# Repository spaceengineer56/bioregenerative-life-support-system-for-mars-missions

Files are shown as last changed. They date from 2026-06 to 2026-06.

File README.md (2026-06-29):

# Биорегенеративная система жизнеобеспечения для межпланетного корабля (БСЖМК)

> Концептуальный инженерный проект автономной биорегенеративной системы жизнеобеспечения для длительных межпланетных миссий.

---

## Обзор

Проект представляет собой концепцию **биорегенеративной системы жизнеобеспечения (BLSS)**, рассчитанной на поддержку экипажа из **10 астронавтов** в течение примерно **1000-дневной миссии на Марс**.

Идея системы основана на замкнутом цикле переработки ресурсов с минимизацией зависимости от поставок с Земли. Все модули спроектированы с учётом размещения внутри гермообъёма **Starship SpaceX**.

---

## Состав проекта

В проект входят:

- инженерные расчёты  
- 3D CAD-модели сделанные в KOMPAS-3D
- физический 3D-печатный прототип  
- исследовательская работа  
- презентационные материалы  

---

# Полная система

Полная компоновка биорегенеративной системы жизнеобеспечения.

<p align="center">
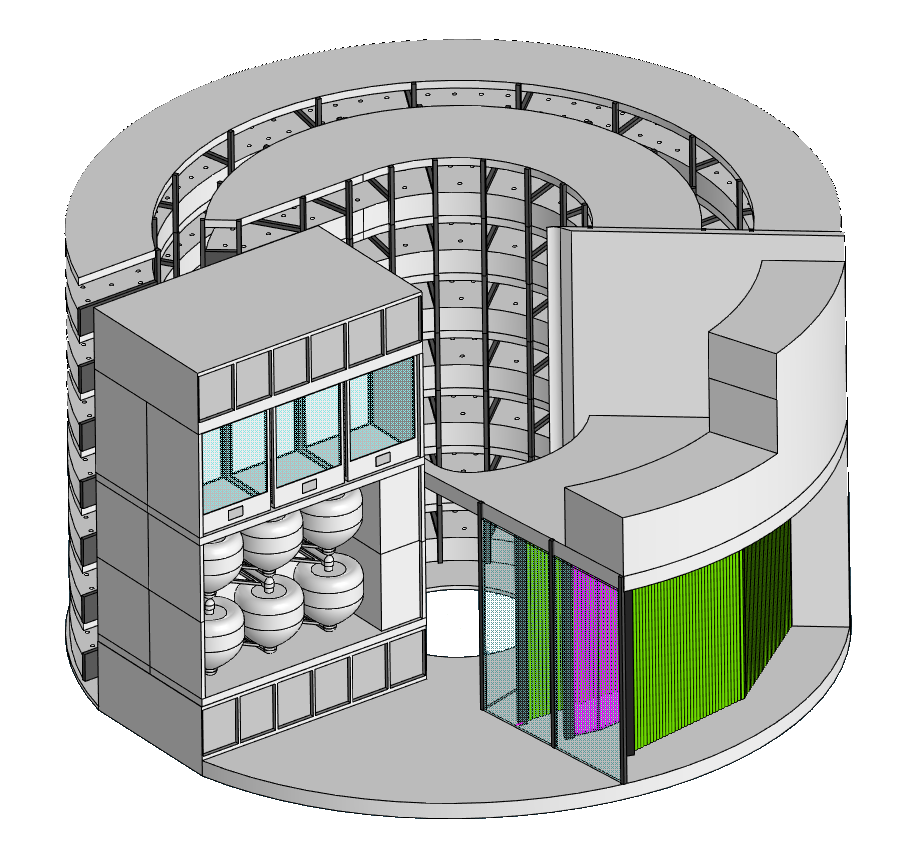
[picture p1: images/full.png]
  
</p>

---

# Основные модули

## Фотобиореактор

Фотобиореактор использует хлореллу для регенерации атмосферы и получения биомассы.

**Функции:**
- выработка кислорода  
- поглощение углекислого газа  
- получение белковой биомассы  

<p align="center">
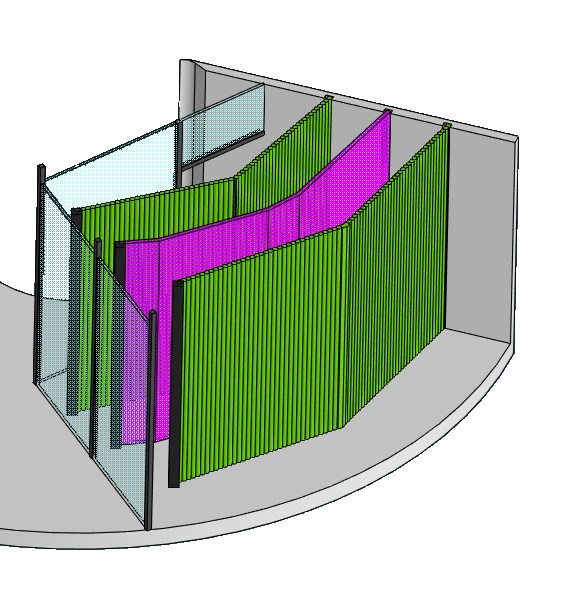
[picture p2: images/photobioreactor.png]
  
</p>

---

## Модуль насекомых

Система переработки органических отходов на основе личинок чёрной львинки.

**Функции:**
- переработка органических отходов  
- получение белка и жиров  
- возврат питательных веществ в цикл  

<p align="center">
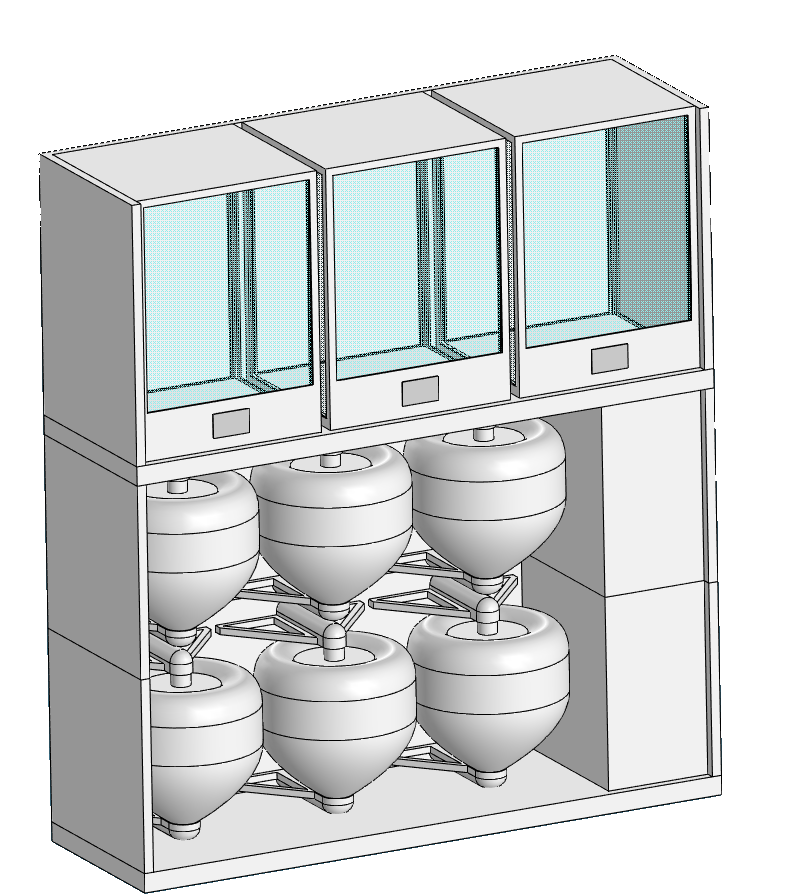
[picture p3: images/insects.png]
  
</p>

---

## Аэропонная теплица

Семиярусная аэропонная теплица для производства пищи.

**Основные культуры:**
- батат
- картошка 

**Дополнительные культуры:**
- пшеница  
- амарант  
- салатные культуры  
- пряные растения
- овощи

<p align="center">
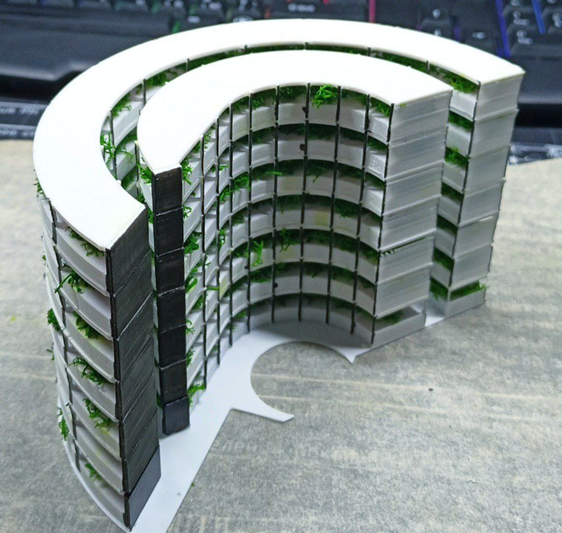
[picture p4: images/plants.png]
  
</p>

---

# Физический прототип

Масштабная демонстрационная модель **1:60**, изготовленная методом **FDM 3D-печати (PLA)**.

Модель была собрана, окрашена и использовалась на защите проекта.

<p align="center">
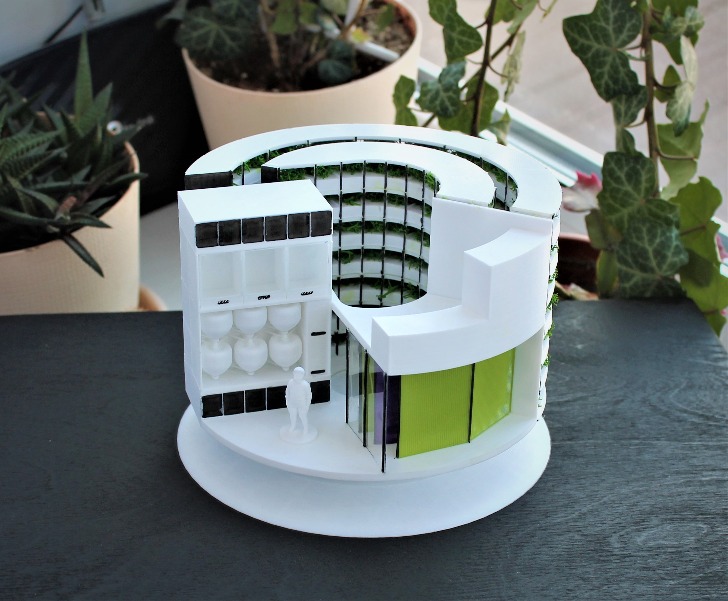
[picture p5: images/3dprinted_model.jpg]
  
</p>

---

# Технические характеристики

| Параметр | Значение |
|---|---|
| Экипаж | 10 человек |
| Длительность миссии | ~1000 суток |
| Объём фотобиореактора | 494 л |
| Производство кислорода | 10.3 кг/сутки |
| Площадь теплицы | 161 м² |
| Модули насекомых | 12 |
| Масштаб прототипа | 1:60 |

---

# Технологии

- KOMPAS-3D  
- инженерные расчёты  
- математическое моделирование  
- FDM 3D-печать  
- PLA  
- CAD-проектирование  

---

# Статус проекта

- ✅ Концепция разработана  
- ✅ Инженерные расчёты выполнены  
- ✅ Создана полная CAD-сборка  
- ✅ Изготовлен физический прототип  

- ⬜ Динамическое моделирование экосистемы  
- ⬜ Система автоматического управления  
- ⬜ CFD и тепловой анализ  

---

# Дальнейшее развитие

Возможные направления развития:

- автоматизация управления средой  
- роботизированное обслуживание модулей  
- оптимизация энергопотребления  
- создание цифрового двойника  
- интеграция с лунными и марсианскими базами  
- долгосрочное моделирование экосистем
- решение проблем с микрогравитацией у фотобиореактора и аэропоники

---

# Примечание

Проект является концептуальным инженерным исследованием и предназначен для образовательных целей.

Система не является готовой к космическому применению, но демонстрирует архитектуру будущих автономных систем жизнеобеспечения.

---

# Автор

**Александр Генералов**

Инженерный концепт биорегенеративной системы жизнеобеспечения для длительных космических миссий.

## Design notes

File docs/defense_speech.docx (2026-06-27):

## Защитная речь

1 слайд: Здравствуйте, уважаемые члены экспертной комиссии! Меня зовут Генералов Александр, и тема моего проекта - «Биорегенеративная система жизнеобеспечения для межпланетного корабля».

2 слайд: Сегодня человечество стоит на пороге колонизации Марса. Однако главная преграда здесь не только радиация и дороговизна, но и проблема с питанием экипажа. Полет в обе стороны и ожидание окна занимают около 1000 дней. Если брать запасы с собой, то на 10 человек потребуется более 150 тонн только еды, воды и кислорода. Это делает миссию почти невозможной.

3 слайд: Цель моей работы - спроектировать систему, которая будет не «складом» ресурсов, а живой фабрикой, восполняющей их прямо на борту. В качестве базы я выбрал габариты корабля Starship диаметром 9 метров.

4 слайд: Чтобы система работала надежно, я выбрал три ключевых биологических звена:

1. Микроводоросли (Хлорелла) – одноклеточные водоросли, лидеры по выработке кислорода.
2. Насекомые (Черная львинка) – похожи на мух, идеальные утилизаторы отходов, превращающие их в жиры и белки.
3. Высшие растения (Батат) – родственник картошки, основной источник углеводов, имеет лучшие показатели урожайности на квадратный метр.

Моя задача как инженера состояла в том, чтобы не просто «расставить горшки с цветами по кораблю», а математически рассчитать, сколько именно нужно этих организмов, чтобы экипаж из 10 человек не испытывал дефицита, и эффективно расположить оборудование в ограниченном объёме.

5 слайд: Мною спроектирована система для разведения хлореллы из 130 герметичных труб. Общий объем составил 494 литра. Мои расчеты показали, что такая установка дает 10 кг кислорода в сутки. Это полностью закрывает потребность 10 человек и дает запас в 2 кг на случай нештатных ситуаций.

6 слайд: Следующая система – устройство для разведения чёрной львинки. Включает в себя террариумы для взрослых особей, инкубаторы для яиц и куколок, и самое интересное – центрифуги для личинок. Главная проблема - отсутствие гравитации, что делает невозможным нормальную вентиляцию субстрата так как массы будут летать по предоставленному объёму и могут забить вентиляцию. Я придумал решение: использовать вращающиеся баки-центрифуги, что устраняет все проблемы. При радиусе 0.4 метра и частоте 33 оборота в минуту внутри создается искусственная гравитация в половину от земной.

7 слайд: Мои расчеты толщины слоя субстрата показывают, что возможно уместить необходимое количество личинок в 6 баков. На случай нештатных ситуаций, решил разместить 12 баков.

8 слайд: Для выращивания батата решил применять аэропонику, так как это позволяет значительно уменьшить массу и увеличить скорость роста. Помимо батата можно выращивать салаты, приправы и цветы. Система дает 2.5 кг углеводов, в сумме с фотобиореактором мы получаем 5 кг углеводов в сутки, что значительно выше необходимого минимума.

9 слайд: На этом слайде представлен расчетный баланс ресурсов системы. В столбике с потребностями – необходимое количество ресурса на 10 человек в сутки, в следующем столбике – максимальное количество, которое производит система жизнеобеспечения. Можно заметить, что везде есть запас, где-то возможно слишком

большой, но в реальности можно будет контролировать производительность.

- 10 слайд: Практическая часть работы заключалась в проектировании системы в Компас-3D и изготовлении макета. Я работал в режиме сборки, чтобы убедиться, что все модули физически вписываются в корпус диаметром 9 метров и высотой 5.5 метров. Для наглядности я изготовил физический макет в масштабе 1 к 60. Для удобства и точности все детали были распечатаны на 3D-принтере, а затем покрашены и склеены. Для возможности рассмотреть систему со всех сторон я использовал вращающуюся базу на подшипнике. Обратите внимание на модель космонавта, которая позволяет оценить реальные размеры системы. Этот макет доказывает, что сложнейшая инженерная система может быть компактно размещена внутри корабля.

11 слайд: Подводя итог, хочу подчеркнуть: разработанная мною модель - это не просто теоретическая концепция. Это просчитанная инженерная структура.

Система полностью автономна по кислороду и обеспечивает запас по углеводам и жирам. Животные и растения не только кормят и поят экипаж, но и создают благоприятный психологический климат, что критически важно в черном вакууме космоса.

В ходе работы остались проблемы с фотобиореактором и аэропоникой. Для стабильной работы в невесомости необходимо сложное оборудование. Но эти проблемы возможно решить, если весь корабль поместить в центрифугу для создания искусственной гравитации.

Биорегенеративные системы - это единственный путь для человечества стать по-настоящему межпланетным видом. Мой проект подтверждает: технически это возможно осуществить в ближайшем будущем.

Спасибо за внимание! Готов ответить на ваши вопросы.

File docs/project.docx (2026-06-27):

Научно-исследовательская работа

Биорегенеративная система жизнеобеспечения для межпланетного корабля

Работу выполнил:

Генералов Александр Дмитриевич

Руководитель:

Генералов Дмитрий Александрович

Орск

2026

Оглавление

1. Введение……………………………………………………………………. | 3
2. Концепция биорегенеративной системы жизнеобеспечения…………… | 5
2.1. Проблема ресурсной автономности марсианской миссии…………...… | 5
2.2 Обоснование выбора базы проектирования…………………………...… | 6
3. Проектирование основных модулей системы…………………………… | 7
3.1. Фотобиореактор: расчет газообмена и конструкция…………………... | 7
3.2. Ферма насекомых: переработка отходов и получение биомассы……… | 8
3.3. Аэропонная оранжерея: культивирование высших растений…………. | 9
4. Техническая реализация и макетирование………………………………... | 10
4.1. Разработка трехмерных моделей в системе Компас-3D……………….. | 10
4.2. Изготовление и сборка демонстрационного макета……………………. | 11
5. Заключение…………………………………………………………………. | 12
6. Список литературы………………………………………………………… | 13

1. Введение

Актуальность работы

Освоение дальнего космоса и подготовка к межпланетным перелетам ставят перед инженерами серьезный вызов: как обеспечить жизнь экипажа в условиях полной изоляции от Земли. Полет к Марсу и обратно вместе с периодом ожидания занимает около трех лет. Транспортировка необходимых запасов на такой срок требует колоссальных грузовых мощностей, что делает миссию технически сложной и дорогой. В связи с этим актуальным становится создание систем воспроизводства ресурсов непосредственно на борту корабля.

Постановка проблемы

Основная трудность заключается в проектировании эффективной замкнутой экосистемы, способной вписаться в габариты современных космических кораблей. В данной работе за основу взяты параметры перспективного корабля Starship компании SpaceX. При внешнем диаметре корпуса 9 метров и высоте полезного жилого пространства около 18 метров, необходимо компактно разместить биологические установки так, чтобы они полностью покрывали потребности группы из 10 человек.

Объект и предмет исследования

Объектом научно-исследовательской работы являются системы жизнеобеспечения для межпланетных кораблей. Предметом исследования выступает расчет параметров и пространственное моделирование модулей (на основе микроводорослей, насекомых и растений) применительно к внутреннему объему корабля Starship.

Цель работы

Теоретически обосновать инженерную структуру биорегенеративной системы в рамках заданных габаритов и изготовить её наглядный маломасштабный макет.

Задачи:

1. Изучить физиологические потребности экипажа из 10 человек в кислороде и пище.
2. Выбрать биологические компоненты для переработки отходов и синтеза ресурсов (хлорелла, черная львинка, батат).
3. Рассчитать необходимые габариты установок, исходя из площади и объема жилого отсека корабля диаметром 9 метров.
4. Спроектировать трехмерные модели всех узлов системы в программе Компас-3D.
5. Изготовить масштабный макет из пластика методом 3D-печати для демонстрации компоновки модулей.

Методы исследования: анализ данных из научных источников, математическое моделирование, 3D-проектирование и макетирование.

2. Концепция биорегенеративной системы жизнеобеспечения

2.1. Проблема ресурсной автономности марсианской миссии

Обеспечение жизнедеятельности экипажа в условиях длительного космического полета является наиболее сложной задачей при планировании миссии на Марс. В отличие от околоземных станций (МКС), где запасы регулярно пополняются грузовыми кораблями, марсианская экспедиция должна обладать беспрецедентным уровнем автономности.

Согласно баллистическим расчетам по траектории Гомана, среднее время миссии составляет около 1000 суток (33 месяца). Основная проблема заключается в массе необходимых расходных материалов. По данным Института медико-биологических проблем РАН (ИМБП РАН), на одного человека в сутки требуется значительный объем кислорода, воды и пищи. При расчете на экипаж из 10 человек суммарный вес запасов превышает 150 тонн. Доставка такой массы с Земли технически очень сложна и экономически неэффективна.

Решением этой проблемы является переход к биорегенеративным системам жизнеобеспечения (БСЖ). Принцип БСЖ заключается в замыкании круговорота веществ: продукты жизнедеятельности человека (углекислый газ, органические отходы) перерабатываются биологическими организмами обратно в кислород и пищу. Это позволяет не только снизить массу корабля, но и создать психологически комфортную среду для экипажа.

2.2. Обоснование выбора базы проектирования

Для того чтобы теоретические расчеты имели прикладной характер, в данной работе в качестве платформы для размещения системы выбран перспективный многоразовый корабль Starship компании SpaceX. На сегодняшний день это единственный проект корабля, способный к межпланетному перелёту и обладающий достаточным внутренним объемом для размещения полнофункциональной биорегенеративной станции.

Таким образом, проектируемая система рассматривается не как абстрактная установка, а как целевое оборудование для конкретного типа межпланетного транспорта. Использование параметров Starship позволяет точно рассчитать компоновку модулей, которая в дальнейшем была визуализирована в 3D-модели и воплощена в масштабном макете.

### 3. Проектирование основных модулей системы

3.1. Фотобиореактор: расчет газообмена и конструкция

Фотобиореактор предназначен для регенерации атмосферы и синтеза белка с использованием микроводоросли хлореллы.

Конструкция и расчет объема: Установка спроектирована в системе Компас-3D и представляет собой блок из 130 герметичных труб диаметром 44 мм и длиной 2,5 м.

- Объем одной трубы: V = 3,14 × 0,022 × 0,022 × 2,5 × 1000 = 3,8 литра.
- Общий объем системы: 3,8 × 130 = 494 литра.

Производительность (суточные показатели): На основе данных проекта «435нм» произведен расчет выхода ресурсов:

- Прирост биомассы: 0,016 × 494 = 7,9 кг хлореллы.
- Генерация кислорода (O2): 1,3 × 7,9 = 10,3 кг (при норме на 10 человек - 8,4 кг).
- Поглощение углекислого газа (CO2): 1,8 × 7,9 = 14,2 кг.
- Пищевая ценность: 4 кг белка и 2,4 кг углеводов.

Таким образом, технические параметры фотобиореактора позволяют не только регенерировать атмосферу, но и обеспечивать экипаж первичной биологической массой. Компактное размещение трубчатых элементов дает возможность рационально использовать внутренний объем, оставляя свободное пространство для работы и отдыха. Применение автоматизированного контроля за освещением и циркуляцией суспензии минимизирует участие человека в работе установки, превращая реактор в стабильный и автономный узел жизнеобеспечения.

3.2. Ферма насекомых: переработка отходов и получение биомассы

В качестве разводимой культуры в проекте выбрана чёрная львинка. Конструктивно ферма состоит из террариумов для взрослых особей (имаго), инкубаторов для яиц и баков-центрифуг для выращивания личинок.

Инженерное решение и расчет вращения: Для решения проблемы дефицита гравитации в космосе личинки содержатся в специальных баках-центрифугах. При вращении субстрат прижимается к стенкам, что упрощает газообмен и вентиляцию. Для создания искусственной гравитации в 0.5g при радиусе бака 0.4 м была рассчитана необходимая угловая скорость: √(0.5 × 9.81 / 0.4) ≈ 3.5 рад/с ≈ 33 об/мин.

Расчет производительности: На основе данных из научного журнала Universum определены суточные показатели выхода биомассы для нужд экипажа:

- Выход сухих личинок: 0.8 × 1.2 / 0.1387 ≈ 6.9 кг в сутки.
- Выход живых личинок: 6.9 / 0.35 ≈ 19.7 кг в сутки.

Баланс субстрата в системе: Для поддержания такого темпа роста требуется ежедневная подача органических отходов:

- 19.7 × 1.6 = 31.52 кг субстрата в сутки.
- 31.52 × 10 = 315.2 кг субстрата постоянно находится в системе (учитывая десятидневный цикл роста личинок).

Параметры бака и толщина слоя: Для эффективного содержания важно соблюдать нормы плотности субстрата. Расчет объема смеси на один из шести основных баков составил 0.0875 м³, что позволило вычислить толщину слоя на стенках: 0.4 - √(0.4² - 0.0875 / (3.14 × 0.4)) ≈ 10 см. Этот показатель соответствует рекомендуемым 10–15 см, что предотвращает перегрев личинок и обеспечивает им стабильный доступ к воздуху.

Для производства необходимого количества жиров физически достаточно 6 баков. Однако для повышения надежности всей системы и возможности обслуживания отдельных узлов в проект заложено 12 аналогичных установок.

3.3. Аэропонная оранжерея: культивирование высших растений

Растительный модуль предназначен для производства сложных углеводов и витаминов, необходимых для сбалансированного рациона экипажа. Конструктивно оранжерея состоит из 7 этажей аэропонных установок, что позволяет получить 161 квадратный метр активной площади для выращивания культур.

Основным источником углеводов в системе выбран батат. Кроме него, для разнообразия питания и восполнения микроэлементов в проект заложены дополнительные культуры: амарант, пшеница, различные виды салатов и приправы.

Расчет производительности: На основе средних показателей урожайности для закрытых аэропонных систем был произведен расчет выхода питательных веществ: 75 × 0.22 ≈ 16 г/м² углеводов в сутки. Для всей доступной площади модуля (161 м²) общая производительность составляет: 161 × 16 ≈ 2.5 кг углеводов в сутки.

Анализ суммарной эффективности: Для обеспечения жизнедеятельности экипажа из 10 человек требуется около 3.2 кг углеводов в сутки. Согласно проектным расчетам, оранжерея и фотобиореактор вместе генерируют почти 5 кг углеводов в сутки (2.5 кг от оранжереи и 2.4 кг от реактора).

Основным источником углеводов в системе выступает оранжерея. Углеводы, получаемые из фотобиореактора, служат резервным ресурсом, который гарантированно восполняет любой возможный недобор и создает запас прочности системы при увеличении физических нагрузок экипажа.

## 4. Техническая реализация и макетирование

4.1. Моделирование узлов в системе Компас-3D

При переходе к этапу трехмерного проектирования в системе Компас-3D за основу были взяты реальные габариты жилого отсека корабля Starship. Цифровая модель всей системы жизнеобеспечения была выстроена в натуральную величину: итоговый диаметр конструкции составил 9 метров, а общая высота всех модулей - 5,5 метра.

Использование режима сборки позволило в реальном масштабе оценить плотность размещения оборудования. Такой подход подтвердил, что выбранные габариты позволяют не только компактно разместить все три биологических модуля, но и оставить достаточное пространство для перемещения экипажа и доступа к техническим узлам.

Процесс моделирования был разделен на несколько этапов:

1. Проектирование фотобиореактора. На основе расчетных данных (внутренний диаметр 44 мм) был создан базовый сегмент трубы. В режиме сборки эти сегменты были размножены до 130 единиц и объединены в общую систему циркуляции с учетом возможности подвода коммуникаций. Для управления режимами освещения реактора предусмотрена стеклянная перегородка с функцией затемнения (смарт-стекло).
2. Разработка фермы черной львинки. Здесь режим сборки позволил точно выставить зазоры для свободного вращения 12 баков-центрифуг. Также были смоделированы стеллажи для эргономичного размещения террариумов и инкубаторов.
3. Моделирование аэропонной оранжереи. На финальном этапе в общую сборку были добавлены семиэтажные стеллажи. В целях оптимизации внутреннего пространства корабля аэропонные установки размещены по дуге в два ряда. Для обеспечения доступа экипажа и удобства обслуживания между рядами предусмотрен технологический проход шириной 60 см.
4. Планировка рабочего пространства. Свободное пространство, оставшееся после компоновки основных модулей, отведено под специализированную зону для хранения инструментария и расходных материалов, необходимых для обслуживания биорегенеративной системы.

4.2. Создание физического макета биорегенеративной системы жизнеобеспечения

Для материализации проекта и создания наглядной демонстрационной модели был выбран масштаб 1:60. Исходя из этого коэффициента, диаметр распечатанного макета составил 150 мм. Выбор такого масштаба обусловлен необходимостью соблюсти баланс: макет остается достаточно компактным для транспортировки и презентации, но при этом сохраняет высокую точность детализации.

Процесс изготовления включал в себя следующие шаги:

- 3D-печать. Все ключевые элементы, спроектированные в Компасе (секции реактора, барабаны фермы, ярусы оранжереи), были распечатаны из PLA-пластика на 3D-принтере Flyingbear Ghost 6.
- Сборка и монтаж. Распечатанные детали были зашлифованы, окрашены и склеены в единую конструкцию. Использование пластика позволило сделать макет легким, но при этом достаточно детализированным для демонстрации внутренних узлов.
- Визуализация. Для наглядности разные функциональные зоны были выделены цветом: балки стеллажей окрашены в черный цвет, элементы фотобиореактора - в зеленый, а зоны освещения выделены фиолетовым. Для реалистичной имитации растительности в оранжерее использован стабилизированный мох.
- Презентабельность и масштаб. Для обеспечения всестороннего обзора макета БСЖМК сконструирована вращающаяся база на подшипниковой опоре. Чтобы зрительно оценить реальные габариты системы и эргономику внутреннего пространства, на макете закреплена фигурка космонавта, выполненная в строгом соответствии с масштабом конструкции.

### 5. Заключение

В ходе выполнения данной научно-исследовательской работы все поставленные цели были успешно достигнуты. Была спроектирована и обоснована автономная система жизнеобеспечения, способная поддерживать жизнедеятельность экипажа из 10 человек в течение 1000-дневной миссии.

На основе проведенных инженерных расчетов и моделирования можно сделать следующие выводы:

1. Фотобиореактор на базе хлореллы объемом 494 литра полностью справляется с регенерацией атмосферы. Его производительность по кислороду (10,3 кг в сутки) перекрывает потребности экипажа и создает необходимый резерв безопасности. Кроме того, реактор служит источником растительного белка.
2. Модуль энтомологической переработки на основе черной львинки успешно решает задачу утилизации органики. Использование 12 баков-центрифуг позволяет получать 1,12 кг жиров в сутки, что является критически важным для сбалансированного рациона в условиях длительной изоляции.
3. Аэропонная оранжерея площадью 161 квадратный метр вместе с фотобиореактором суммарно обеспечивают около 5 кг углеводов в сутки при норме в 3,2 кг. Это доказывает, что система способна самостоятельно снабжать экипаж пищей без необходимости везти с собой огромные запасы провизии с Земли.

Разработанный макет демонстрирует возможную структуру биорегенеративной системы жизнеобеспечения для длительных межпланетных миссий. Использование биологических компонентов, таких как растения и насекомые, открывает новые возможности в космонавтике. Проведённые расчёты показали, что подобная система может самостоятельно обеспечивать экипаж кислородом и пищей, снижая массу необходимых запасов и повышая автономность миссии. Кроме того, наличие растений может оказывать положительное психологическое влияние на экипаж во время длительного пребывания в космосе.

Таким образом, биорегенеративные системы жизнеобеспечения являются перспективным направлением для будущих межпланетных экспедиций. Работа над макетом в системе Компас-3D и его физическое воплощение подтвердили техническую реализуемость предложенных идей и их готовность к дальнейшему развитию.

### 6. Список литературы

### 1. Синяк, Ю. Е. (2008). Системы жизнеобеспечения обитаемых космических объектов (прошлое, настоящее и будущее). Доступно по ссылке: http://www.imbp.ru/webpages/win1251/science/uchsov/docl/2008/Sinjak_speach.html

2. Шаенко, А. Ю. (2023). Биотехническая система обеспечения газового состава атмосферы лунной базы на основе микроводорослей. Доступно по ссылке: https:// (https://docs.google.com/presentation/d/1fhkI-y-zyXAAe3G4RmqY4vzgqxQgFG3P/edit?slide=id.p1)docs.google.com/presentation/d/1fhkI-y-zyXAAe3G4RmqY4vzgqxQgFG3P/edit?slide=id.p1#slide=id.p1

### 3. Туйчиев, К. С. (2023). Выращивание личинок чёрной львинки (Hermetia illucens Linnaeus) на пшеничных отрубях и показатели их продуктивности. Доступно по ссылке: https://7universum.com/pdf/nature/6(108)%20[25.05.2023]/Tuychiev.pdf

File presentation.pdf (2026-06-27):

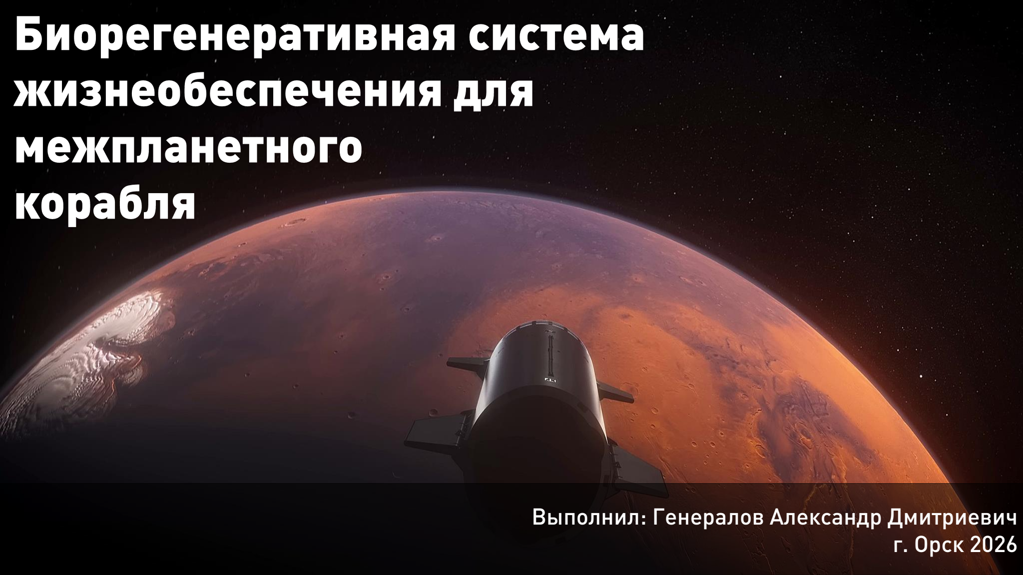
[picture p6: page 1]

Выполнил: Генералов Александр Дмитриевич г. Орск 2026

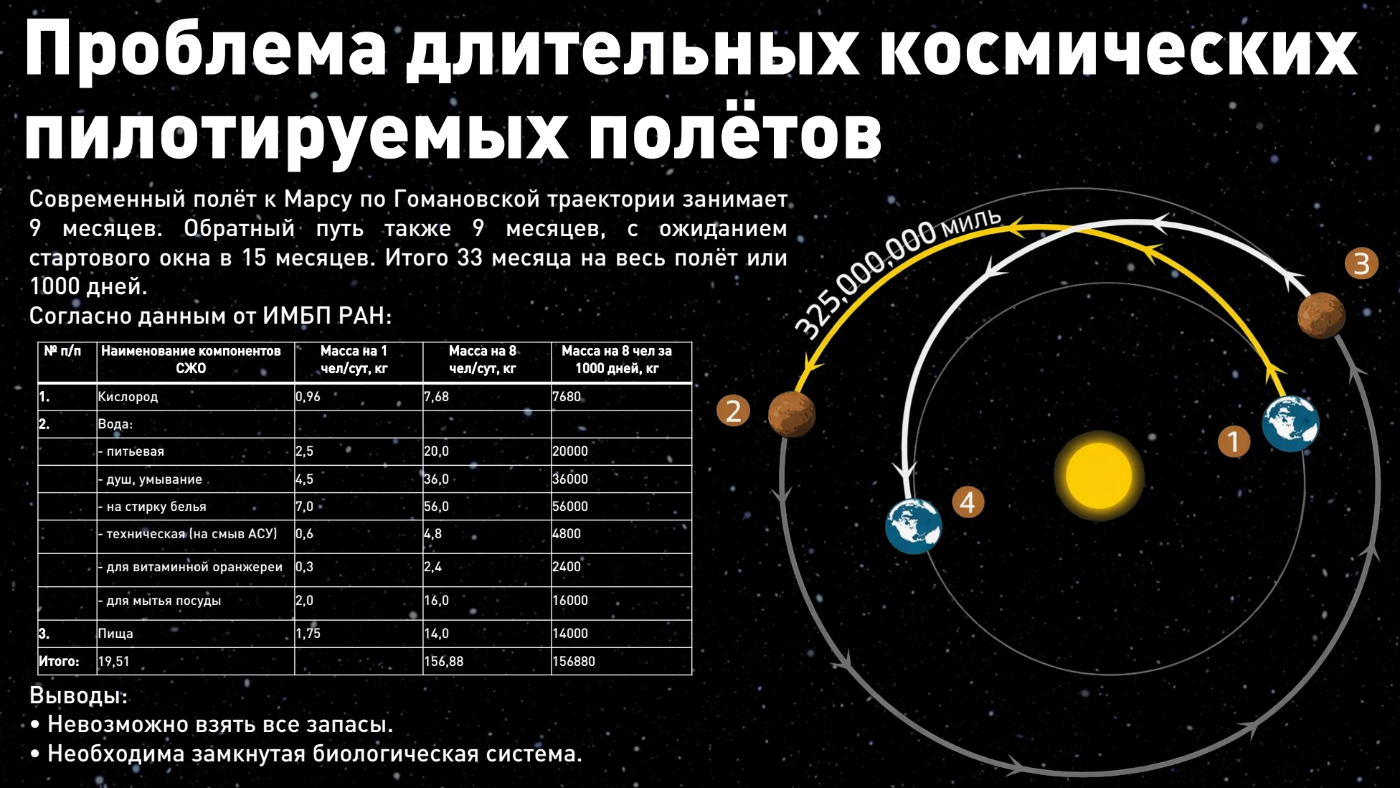
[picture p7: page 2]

Современный полёт к Марсу по Гомановской траектории занимает 9 месяцев. Обратный путь также 9 месяцев, с ожиданием стартового окна в 15 месяцев. Итого 33 месяца на весь полёт или 1000 дней.
Согласно данным от ИМБП РАН:

Выводы:
- Невозможно взять все запасы.
- Необходима замкнутая биологическая система.
№ п/п | Наименование компонентов СЖО | Масса на 1 чел/сут, кг | Масса на 8 чел/сут, кг | Масса на 8 чел за 1000 дней, кг
1. | Кислород | 0,96 | 7,68 | 7680
2. Вода:
| - питьевая | 2,5 | 20,0 | 20000
| - душ, умывание | 4,5 | 36,0 | 36000
| - на стирку белья | 7,0 | 56,0 | 56000
| - техническая (на смыв АСУ) | 0,6 | 4,8 | 4800
| - для витаминной оранжереи | 0,3 | 2,4 | 2400
| - для мытья посуды | 2,0 | 16,0 | 16000
3. | Пища | 1,75 | 14,0 | 14000
Итого: | 19,51 | | 156,88 | 156880

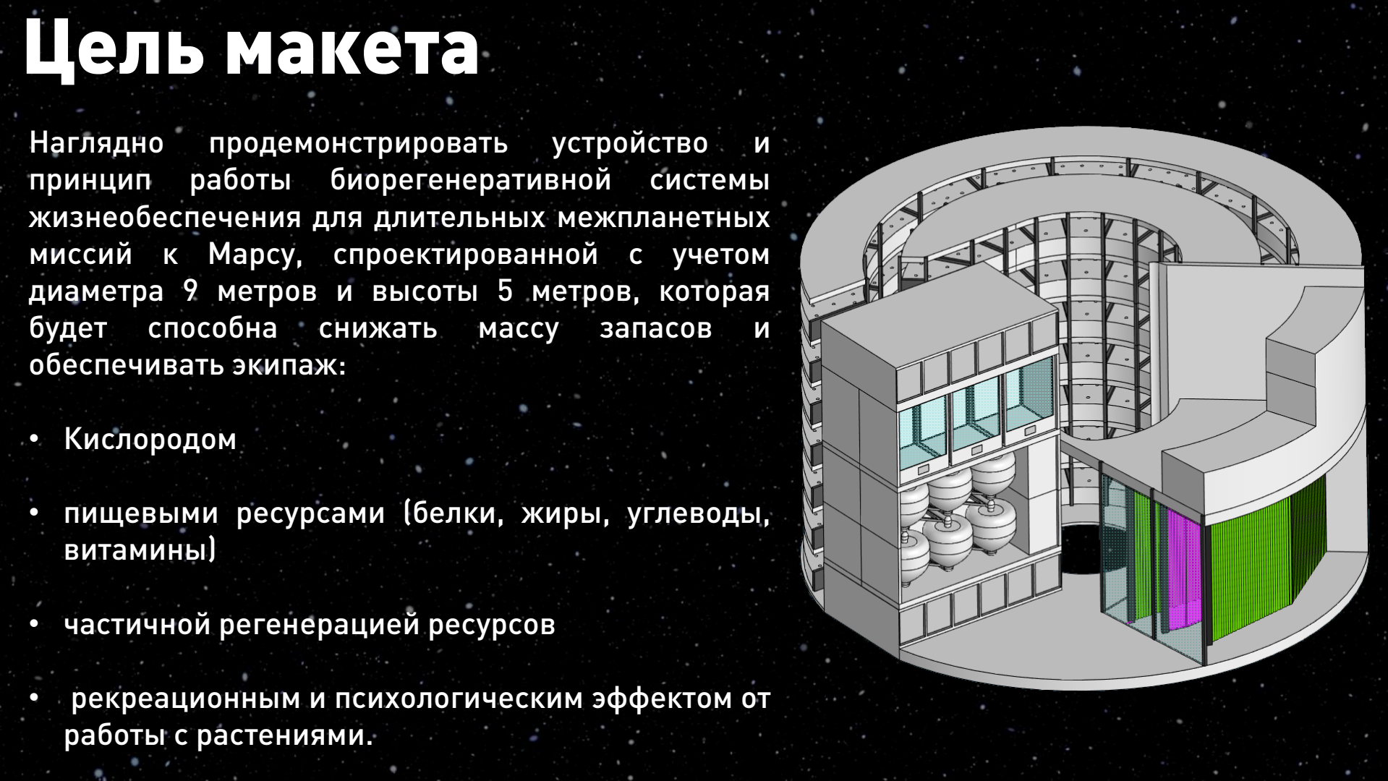
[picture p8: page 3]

Наглядно | продемонстрировать | устройство | и
принцип | работы | биорегенеративной | системы
жизнеобеспечения для длительных межпланетных миссий к Марсу, спроектированной с учетом диаметра 9 метров и высоты 5 метров, которая
будет | способна | снижать | массу | запасов | и
обеспечивать экипаж:
- Кислородом
- пищевыми ресурсами (белки, жиры, углеводы, витамины)
- частичной регенерацией ресурсов
- рекреационным и психологическим эффектом от работы с растениями.

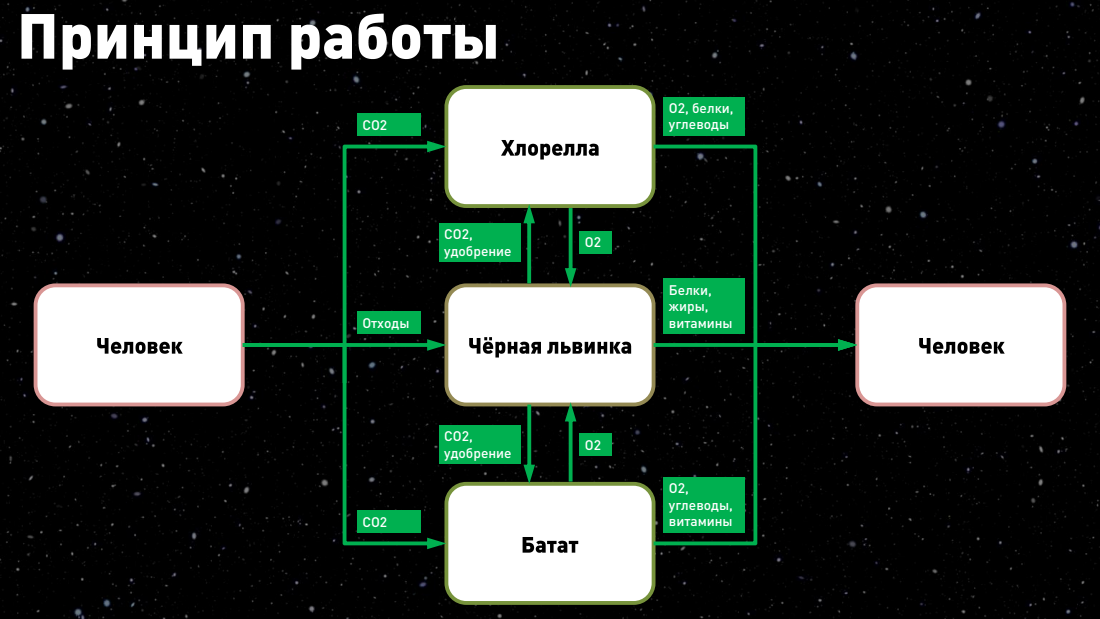
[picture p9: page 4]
O2 CO2, удобрение; Отходы; Белки, жиры, витамины; O2, белки, углеводы; O2, углеводы, витамины

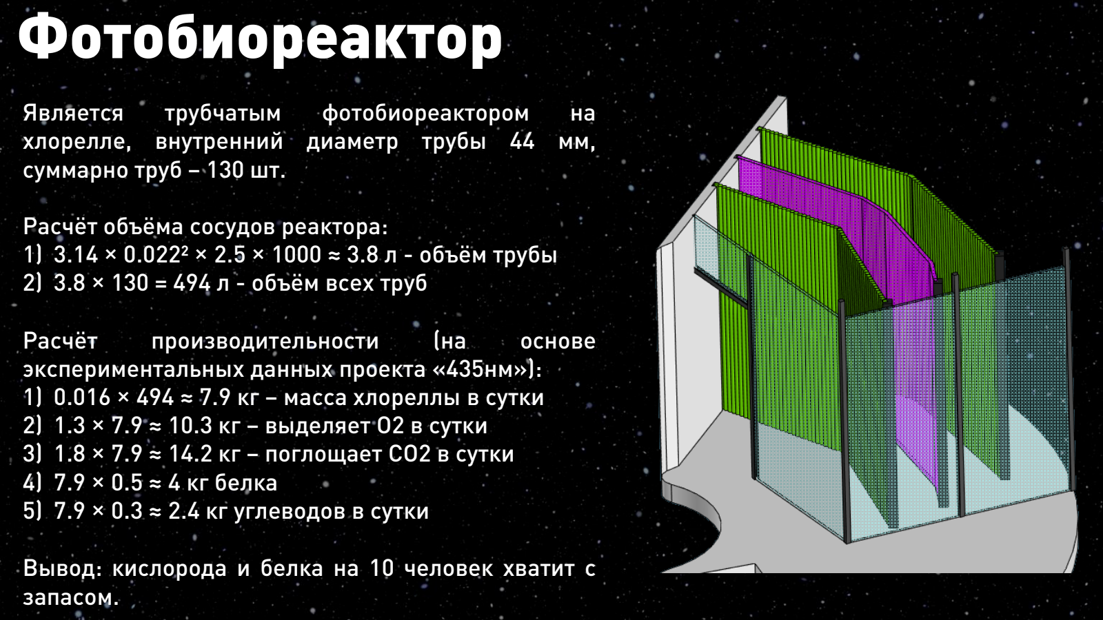
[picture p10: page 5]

Является | трубчатым | фотобиореактором | на
хлорелле, внутренний диаметр трубы 44 мм, суммарно труб – 130 шт.

Расчёт объёма сосудов реактора:
1) 3.14 × 0.022² × 2.5 × 1000 ≈ 3.8 л - объём трубы
2) 3.8 × 130 = 494 л - объём всех труб
Расчёт | производительности | (на | основе
экспериментальных данных проекта «435нм»):
1) 0.016 × 494 ≈ 7.9 кг – масса хлореллы в сутки
2) 1.3 × 7.9 ≈ 10.3 кг – выделяет O2 в сутки
3) 1.8 × 7.9 ≈ 14.2 кг – поглощает CO2 в сутки
4) 7.9 × 0.5 ≈ 4 кг белка
5) 7.9 × 0.3 ≈ 2.4 кг углеводов в сутки

Вывод: кислорода и белка на 10 человек хватит с запасом.

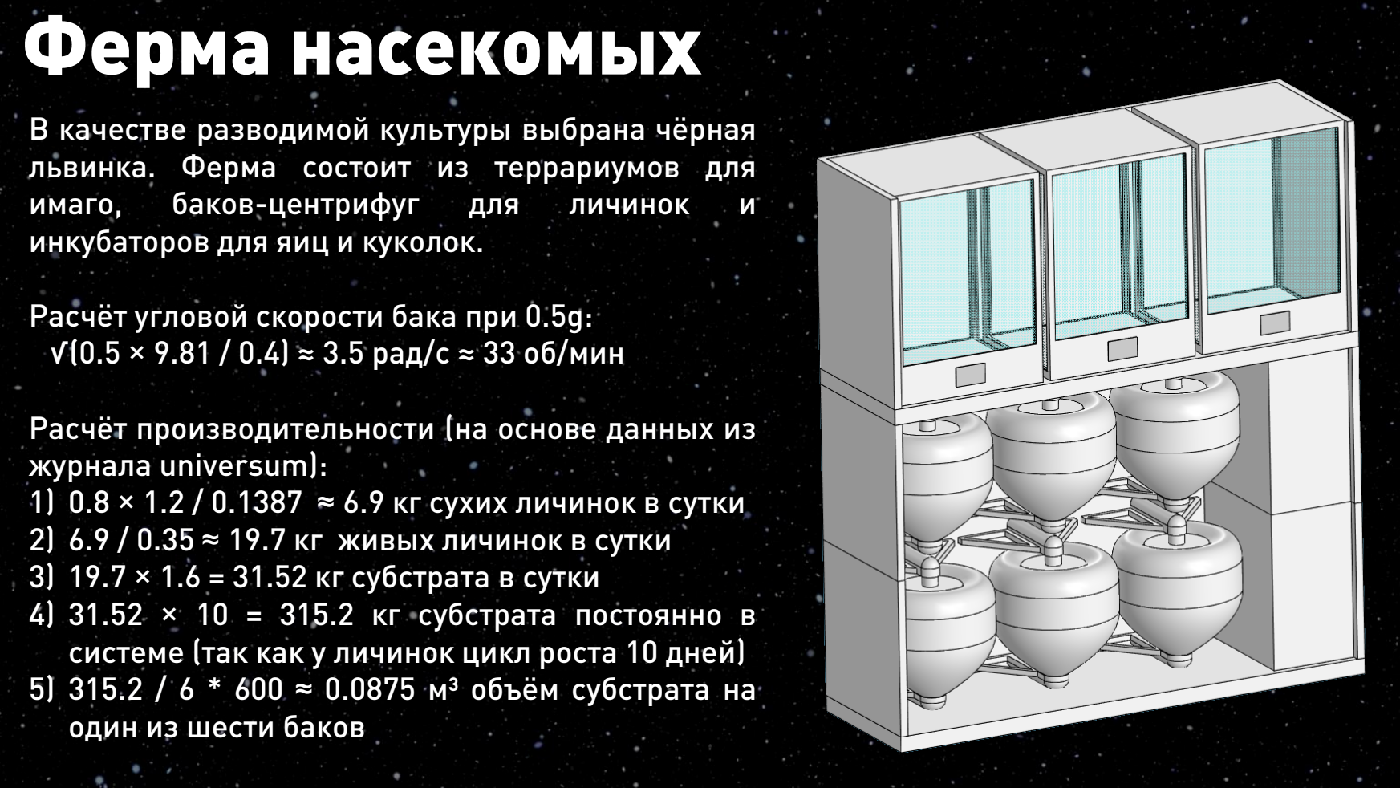
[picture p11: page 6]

В качестве разводимой культуры выбрана чёрная львинка. Ферма состоит из террариумов для
имаго, | баков-центрифуг | для | личинок | и
инкубаторов для яиц и куколок.

Расчёт угловой скорости бака при 0.5g:
√(0.5 × 9.81 / 0.4) ≈ 3.5 рад/с ≈ 33 об/мин

Расчёт производительности (на основе данных из журнала universum):
1) 0.8 × 1.2 / 0.1387 ≈ 6.9 кг сухих личинок в сутки
2) 6.9 / 0.35 ≈ 19.7 кг живых личинок в сутки
3) 19.7 × 1.6 = 31.52 кг субстрата в сутки
4) 31.52 × 10 = 315.2 кг субстрата постоянно в системе (так как у личинок цикл роста 10 дней)
5) 315.2 / 6 * 600 ≈ 0.0875 м³ объём субстрата на один из шести баков

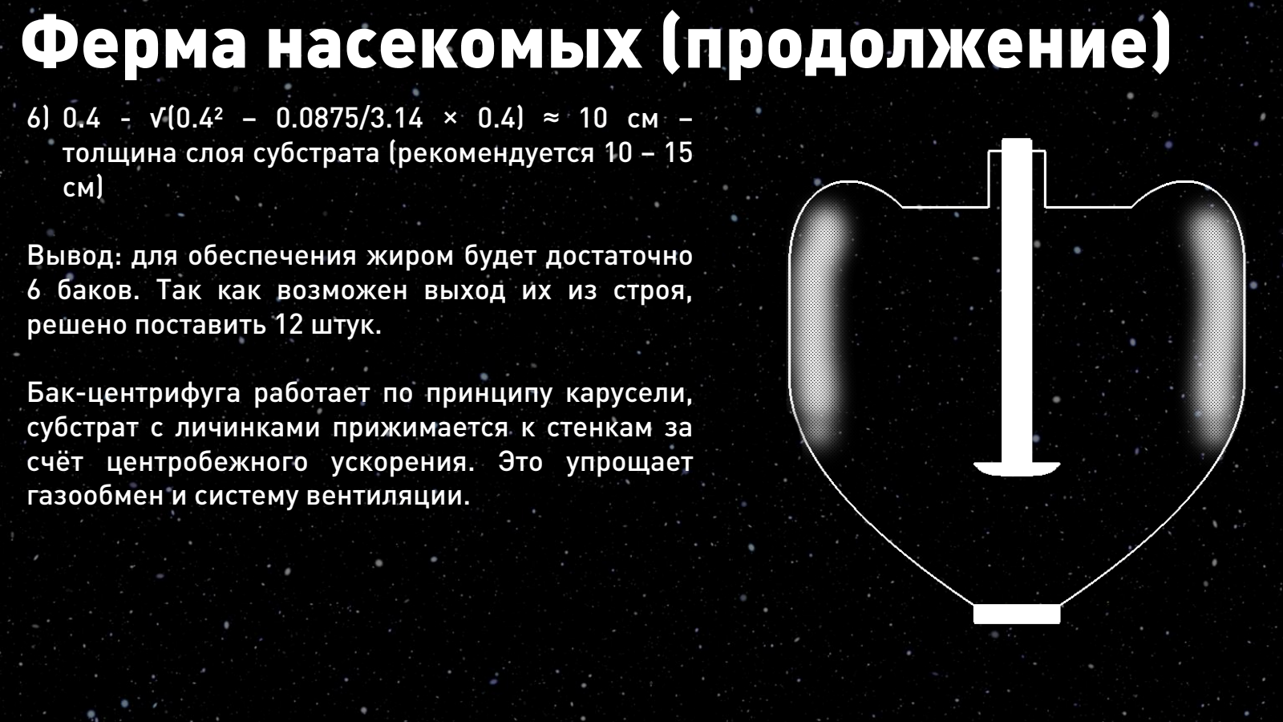
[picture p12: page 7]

6) 0.4 - √(0.4² – 0.0875/3.14 × 0.4) ≈ 10 см – толщина слоя субстрата (рекомендуется 10 – 15 см)

Вывод: для обеспечения жиром будет достаточно 6 баков. Так как возможен выход их из строя, решено поставить 12 штук.

Бак-центрифуга работает по принципу карусели, субстрат с личинками прижимается к стенкам за счёт центробежного ускорения. Это упрощает газообмен и систему вентиляции.

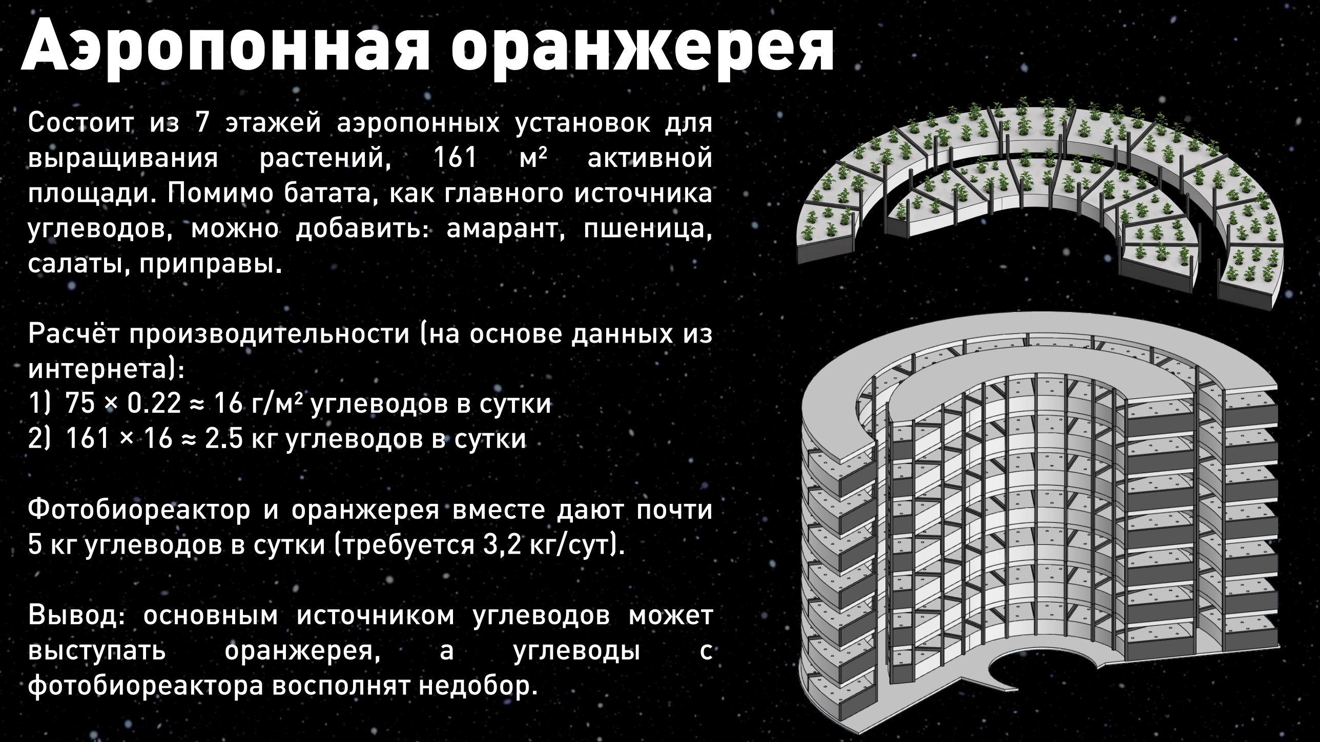
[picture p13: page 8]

Состоит из 7 этажей аэропонных установок для
выращивания | растений, | 161 | м² | активной
площади. Помимо батата, как главного источника углеводов, можно добавить: амарант, пшеница, салаты, приправы.

Расчёт производительности (на основе данных из интернета):
1) 75 × 0.22 ≈ 16 г/м² углеводов в сутки
2) 161 × 16 ≈ 2.5 кг углеводов в сутки

Фотобиореактор и оранжерея вместе дают почти 5 кг углеводов в сутки (требуется 3,2 кг/сут).

Вывод: основным источником углеводов может
выступать | оранжерея, | а | углеводы | с
фотобиореактора восполнят недобор.

Ресурс | Потребность | Производство
O2 | 8.4 кг | 10.3 кг

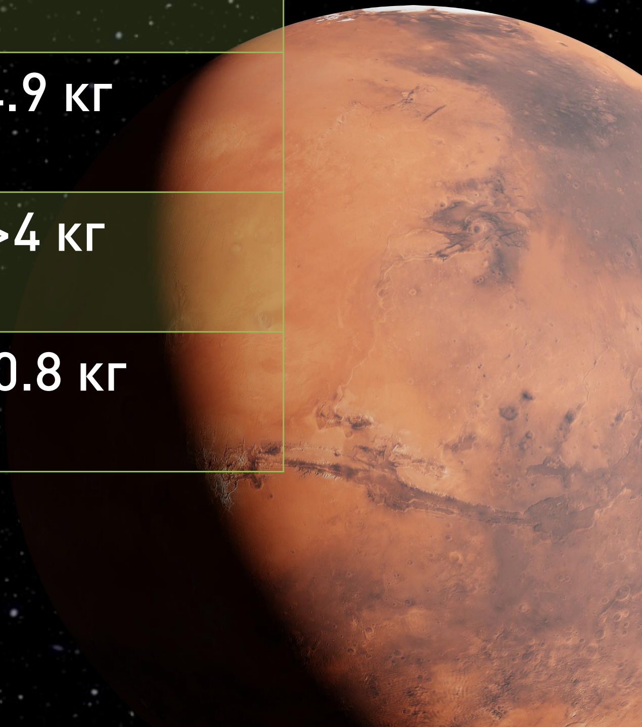
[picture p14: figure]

Углеводы | 3.2 кг | 4.9 кг
Белки | 1 кг | >4 кг
Жиры | 0.8 кг | >0.8 кг

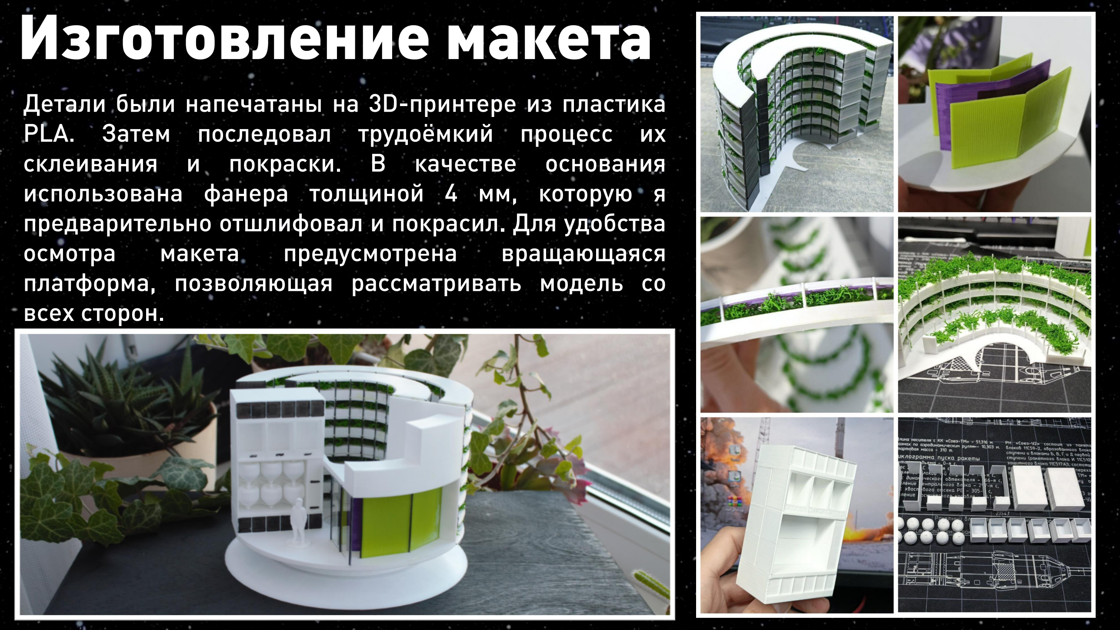
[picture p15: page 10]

Детали были напечатаны на 3D-принтере из пластика PLA. Затем последовал трудоёмкий процесс их
склеивания | и | покраски. | В | качестве | основания
использована фанера толщиной 4 мм, которую я предварительно отшлифовал и покрасил. Для удобства
осмотра | макета | предусмотрена | вращающаяся
платформа, позволяющая рассматривать модель со всех сторон.

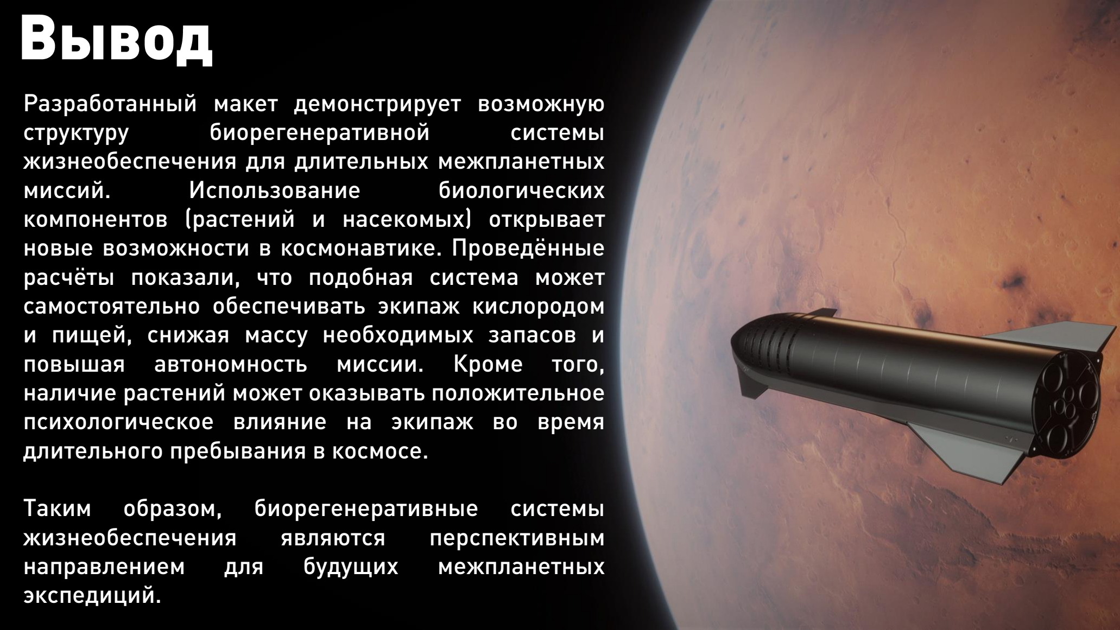
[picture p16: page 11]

Разработанный макет демонстрирует возможную
структуру | биорегенеративной | системы
жизнеобеспечения для длительных межпланетных
миссий. | Использование | биологических
компонентов (растений и насекомых) открывает новые возможности в космонавтике. Проведённые расчёты показали, что подобная система может самостоятельно обеспечивать экипаж кислородом и пищей, снижая массу необходимых запасов и
повышая | автономность | миссии. | Кроме | того,
наличие растений может оказывать положительное психологическое влияние на экипаж во время длительного пребывания в космосе.
Таким | образом, | биорегенеративные | системы
жизнеобеспечения | являются | перспективным
направлением | для | будущих | межпланетных
экспедиций.

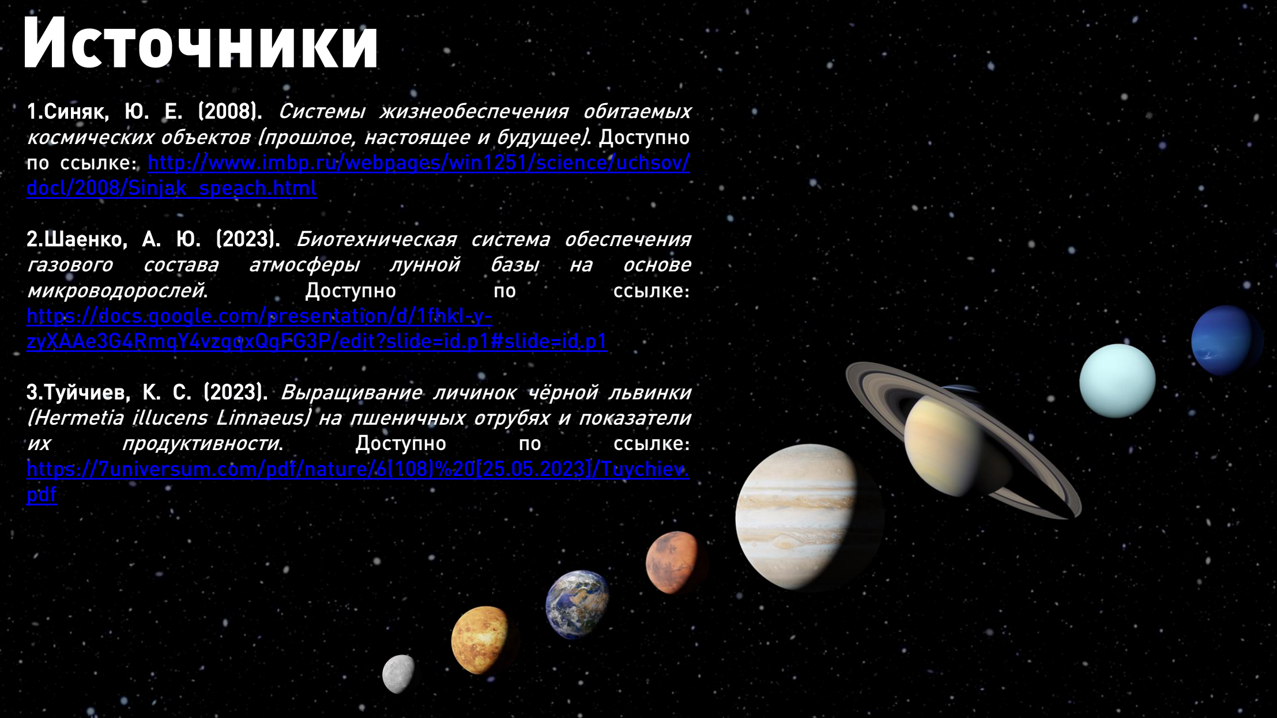
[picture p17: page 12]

1.Синяк, Ю. Е. (2008). Системы жизнеобеспечения обитаемых космических объектов (прошлое, настоящее и будущее). Доступно по ссылке: http://www.imbp.ru/webpages/win1251/science/uchsov/docl/2008/Sinjak_speach.html (http://www.imbp.ru/webpages/win1251/science/uchsov/docl/2008/Sinjak_speach.html)

2.Шаенко, А. Ю. (2023). Биотехническая система обеспечения
газового | состава | атмосферы | лунной | базы | на | основе
микроводорослей. | Доступно | по | ссылке:
https://docs.google.com/presentation/d/1fhkI-y-zyXAAe3G4RmqY4vzgqxQgFG3P/edit?slide=id.p1#slide=id.p1 (https://docs.google.com/presentation/d/1fhkI-y-zyXAAe3G4RmqY4vzgqxQgFG3P/edit?slide=id.p1)

3.Туйчиев, К. С. (2023). Выращивание личинок чёрной львинки (Hermetia illucens Linnaeus) на пшеничных отрубях и показатели
их | продуктивности. | Доступно | по | ссылке:
https://7universum.com/pdf/nature/6(108)%20[25.05.2023]/Tuychiev. pdf

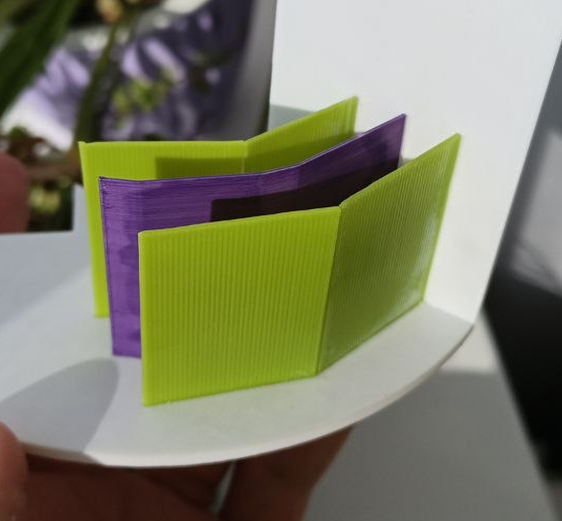
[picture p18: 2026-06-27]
images/Рисунок2.png

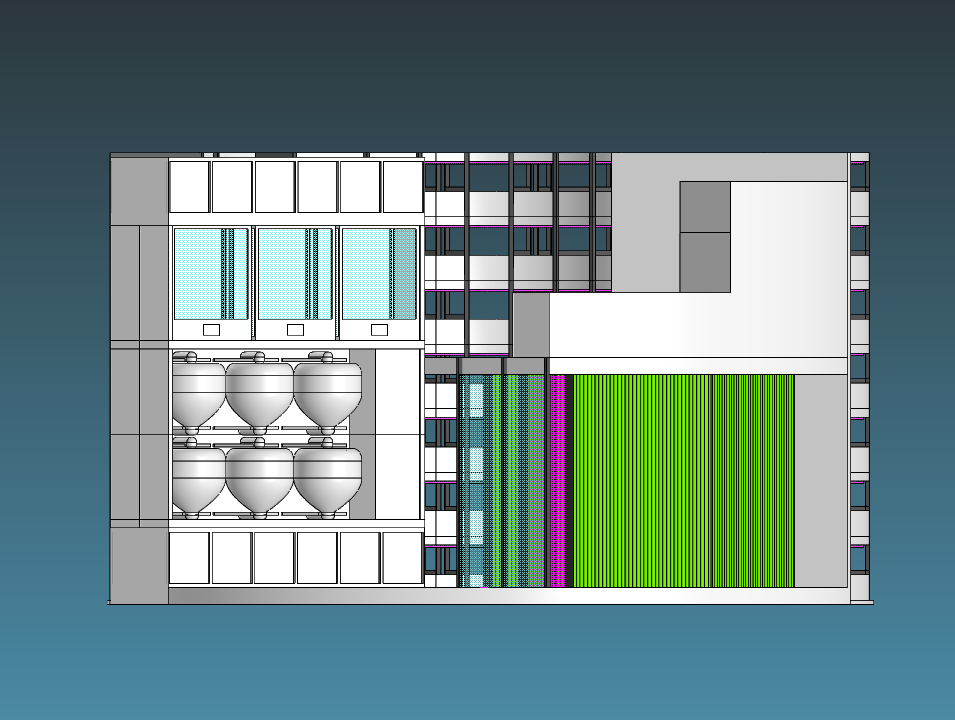
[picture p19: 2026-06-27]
images/Screenshot_5.png

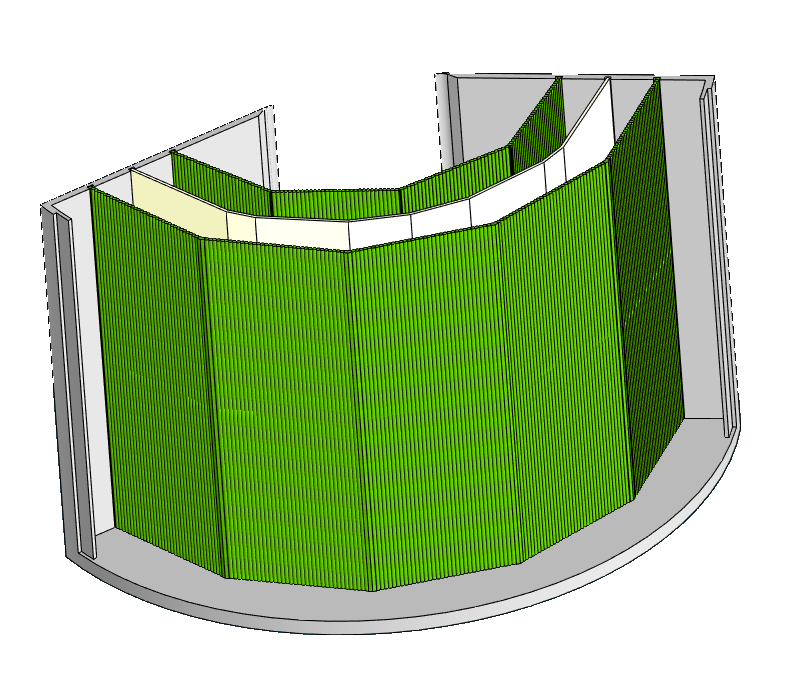
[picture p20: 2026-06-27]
images/Screenshot_3.png

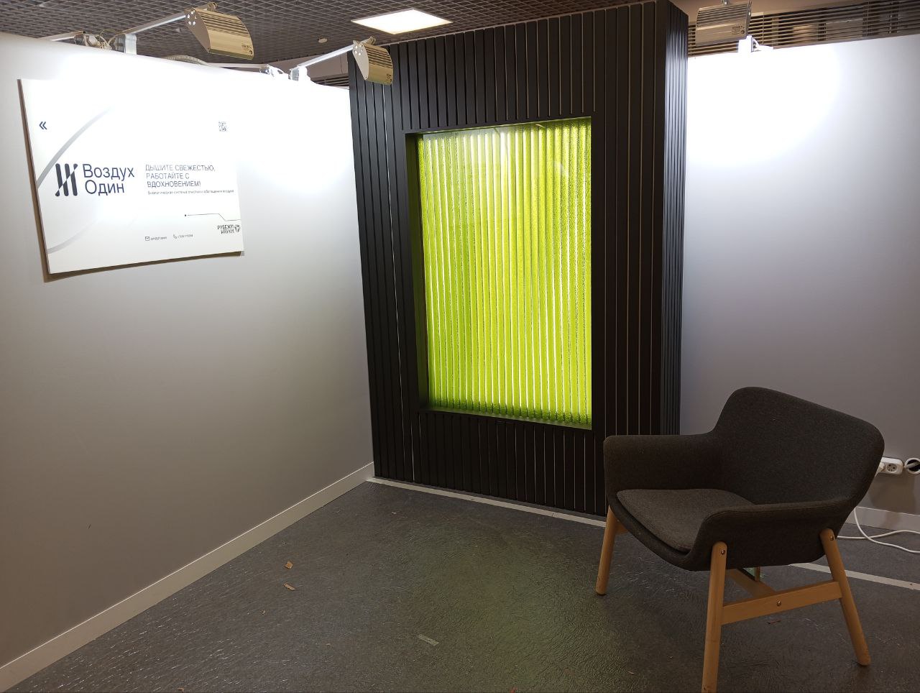
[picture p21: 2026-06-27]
images/shaenko_photobio.jpg

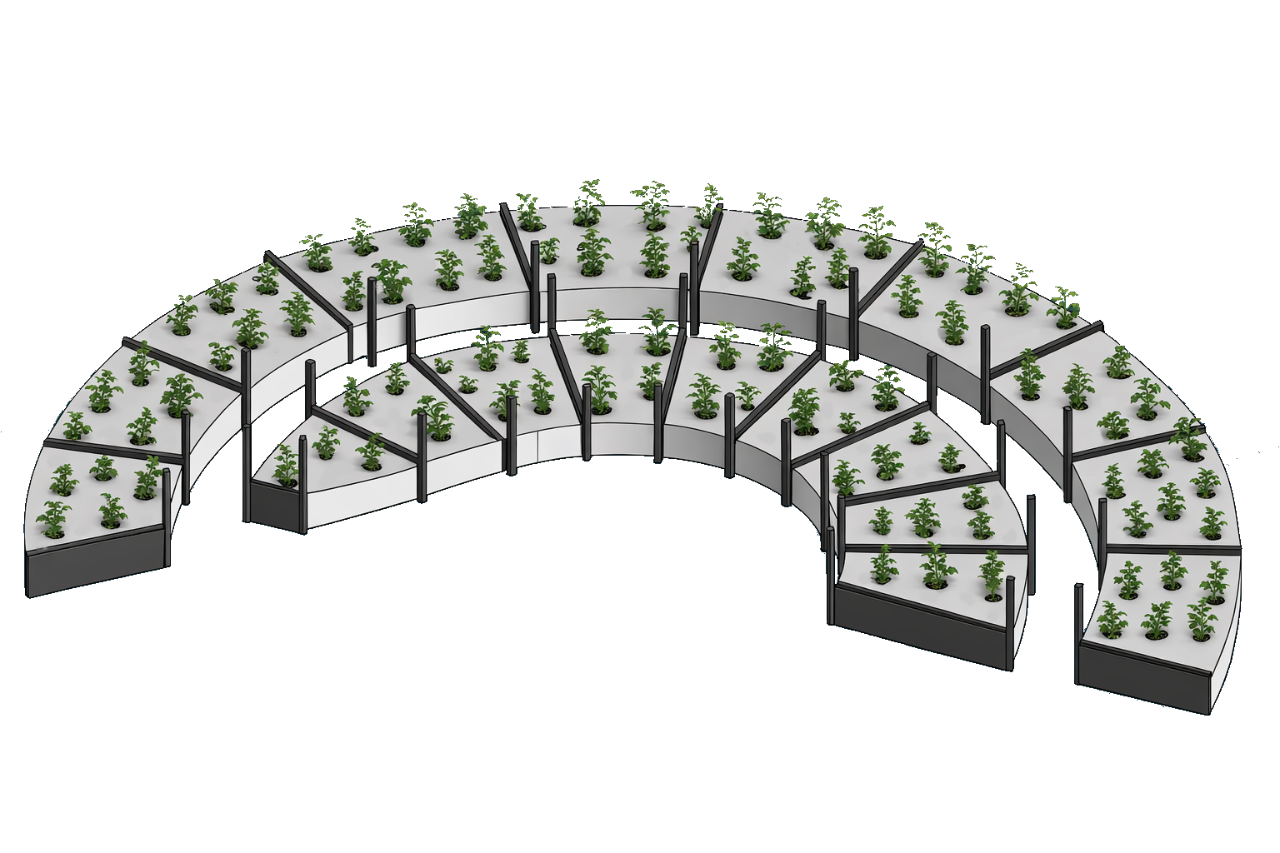
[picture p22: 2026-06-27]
images/ChatGPT Image Mar 9, 2026, 01_15_27 AM.png

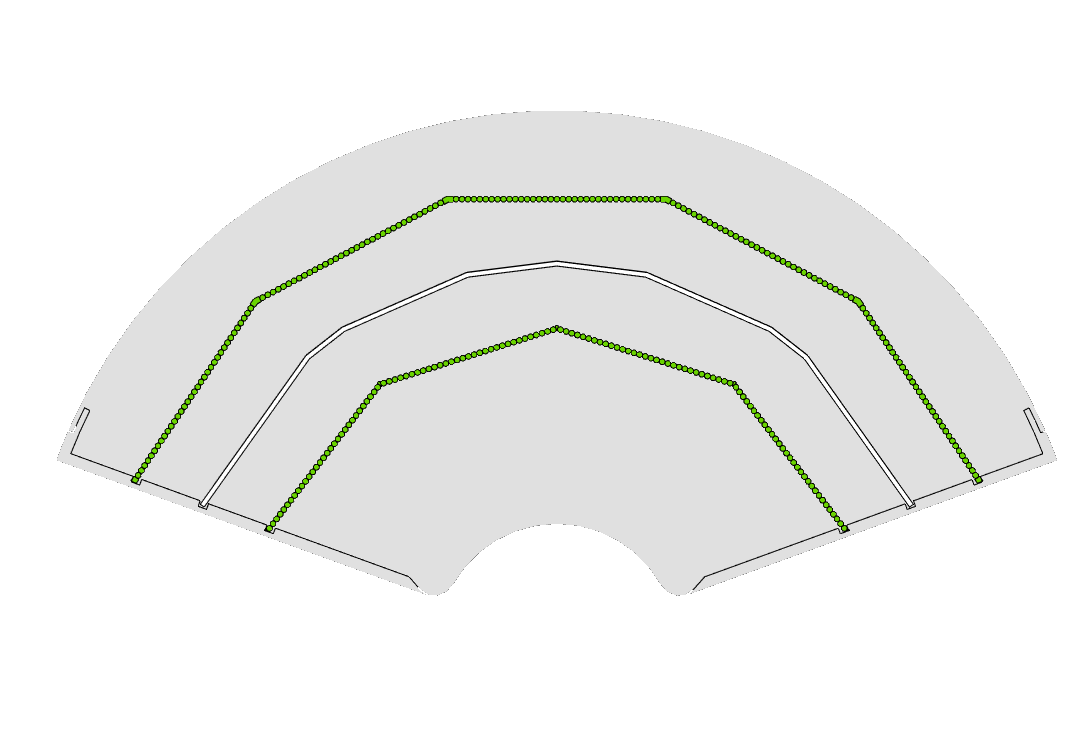
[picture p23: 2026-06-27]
images/Screenshot_2.png

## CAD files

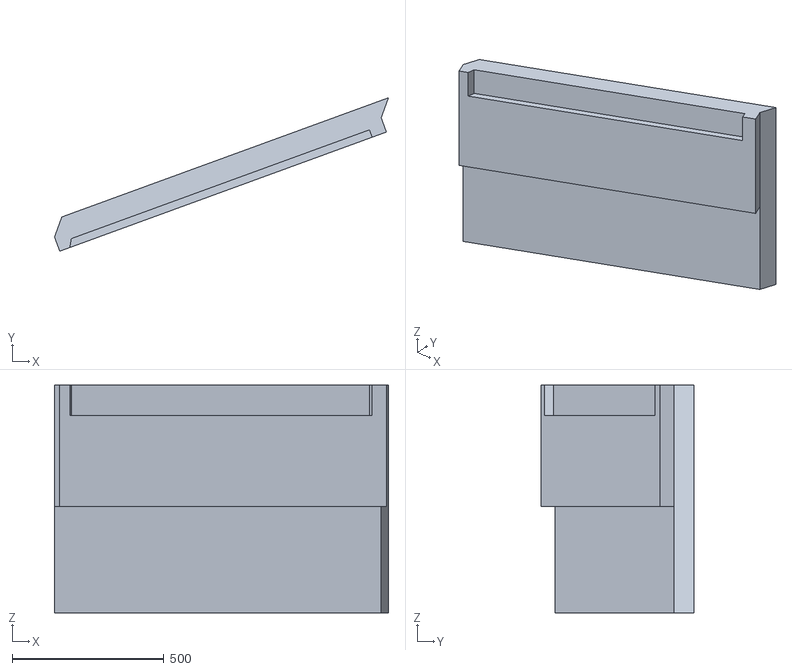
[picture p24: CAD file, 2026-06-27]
CAD/aeroponic/Доп опора 1.stl
1099.7 x 505.2 x 750.0

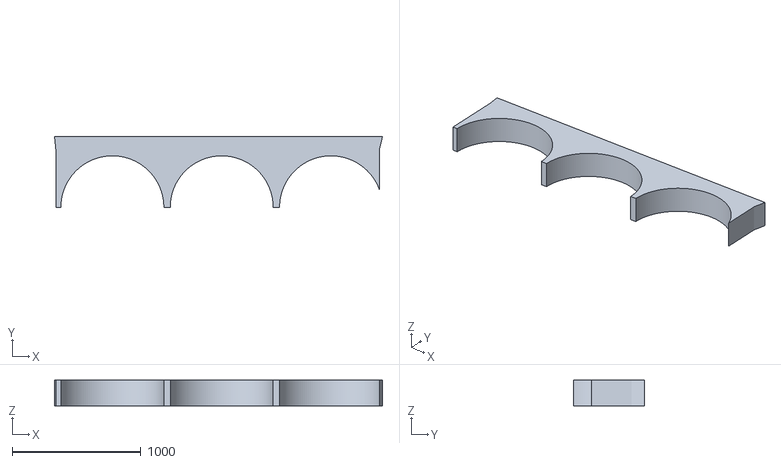
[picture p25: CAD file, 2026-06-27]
CAD/insects/Юстировка баков.stl
2550.0 x 548.8 x 200.0

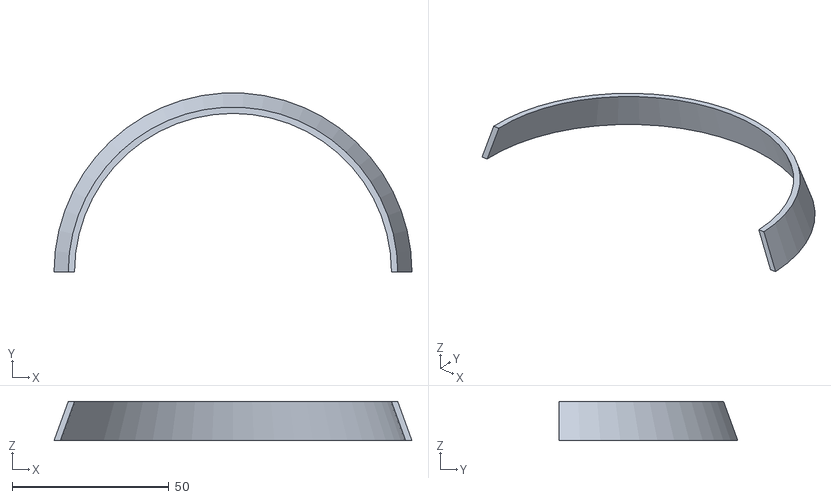
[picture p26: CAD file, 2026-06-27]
CAD/other/верх платформы дуга.stl
114.2 x 57.0 x 12.5

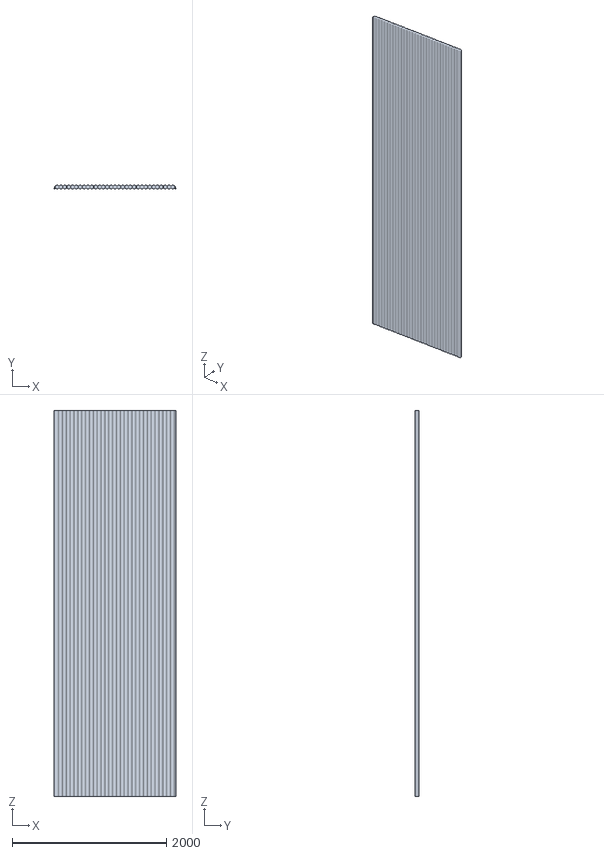
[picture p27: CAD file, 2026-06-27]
CAD/photobioreactor/Сегмент_средн_сегмент.stl
1579.4 x 50.0 x 5000.0

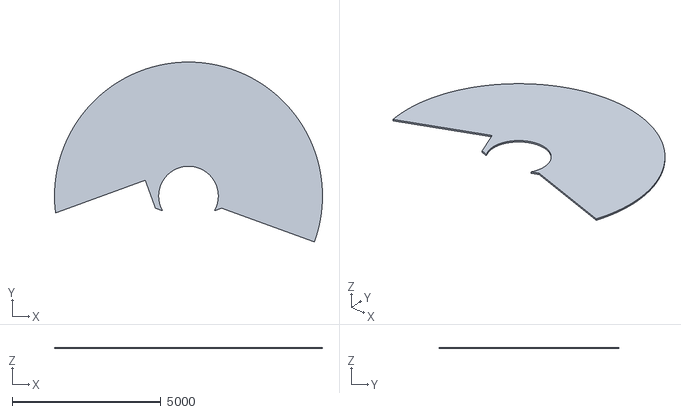
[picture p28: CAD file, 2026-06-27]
CAD/aeroponic/Пол.stl
9000.6 x 6040.4 x 50.0

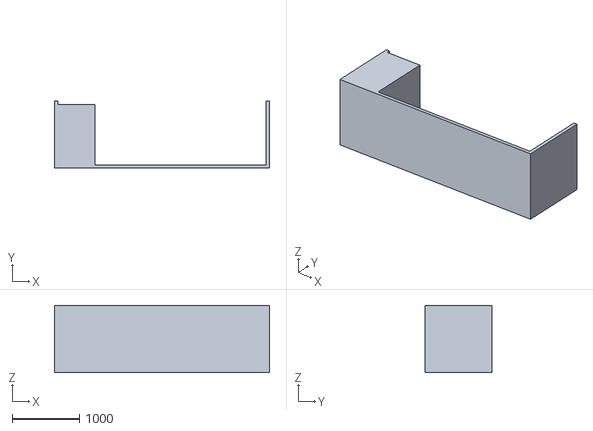
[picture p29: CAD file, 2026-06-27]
CAD/insects/Этаж для центрифуг.stl
3200.0 x 998.8 x 1000.0

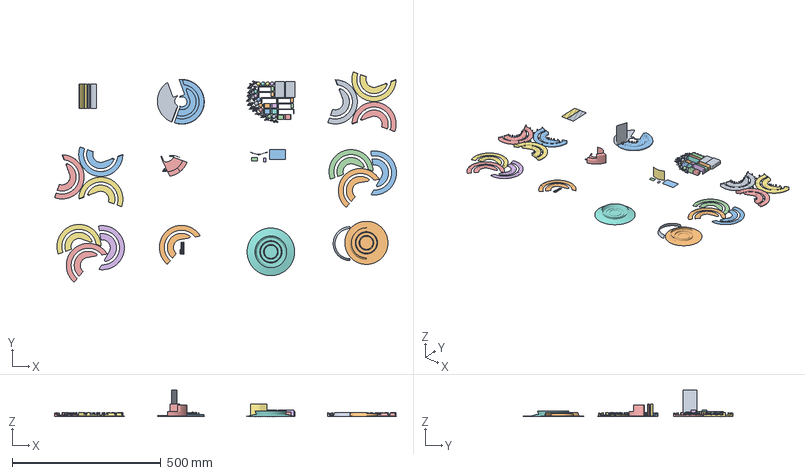
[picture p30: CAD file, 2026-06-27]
CAD/other/Проект для 3д принтера.3mf
1149.0 x 706.3 x 89.6 mm
Сегмент_внешн_сегмент.stl
Свет.stl x 7
Переборка между лич и тер.stl
Слобик остекления.stl x 4
Рабочее место.stl
Освещение правильное.stl
Дно ящики.stl
Слобик остекления мал.stl
Доп опора 1.stl
Освещение внутр.stl
Доп опора 2.stl
Сборка этаж с балками.stl x 6
Сегмент для личинок держалка 2.stl x 13
Ящики верх.stl
Этаж для центрифуг.stl x 4
Стенки терр.stl x 2
Сборка пол с балками и этажом.stl
Террариум.stl x 6
Сегмент_средн_сегмент.stl
Фотобиореактор_база.stl
Сегмент для личинок цилиндр.stl x 12
Сегмент для личинок держалка 1.stl x 12
основание платформы.stl
верх платформы дуга.stl
верх платформы.stl

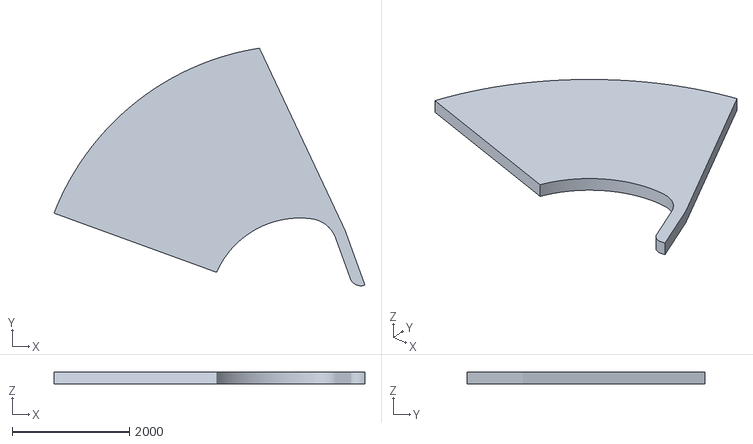
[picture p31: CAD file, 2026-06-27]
CAD/photobioreactor/Перегородка.stl
5305.2 x 4054.1 x 200.0

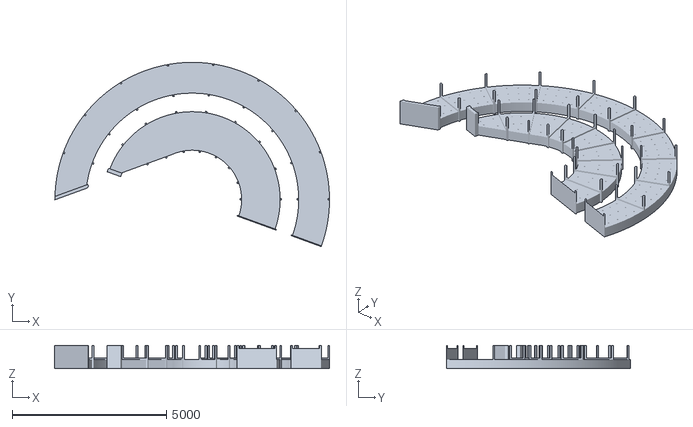
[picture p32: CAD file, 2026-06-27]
CAD/aeroponic/Сборка этаж с балками.stl
8914.1 x 5973.0 x 750.0

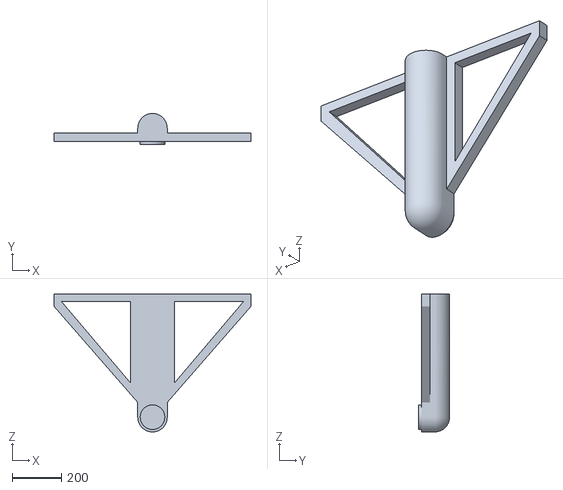
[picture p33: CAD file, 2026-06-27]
CAD/insects/Сегмент для личинок держалка 1.stl
800.0 x 126.5 x 559.9

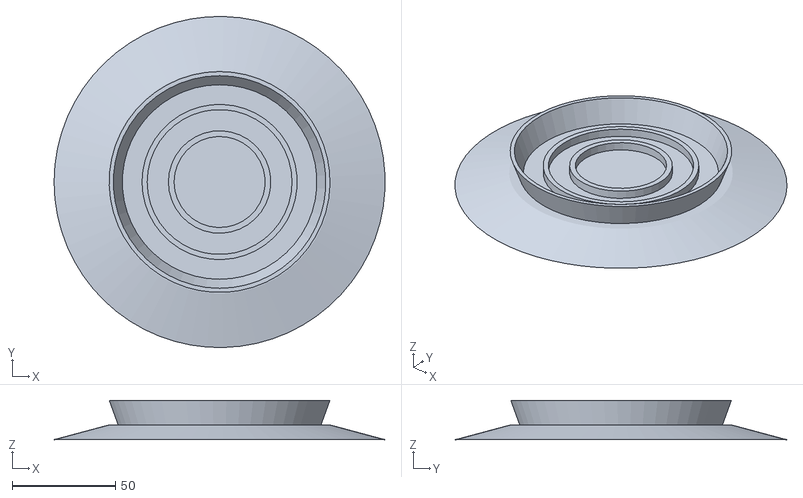
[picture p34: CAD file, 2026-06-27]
CAD/other/основание платформы.stl
159.9 x 160.0 x 19.0

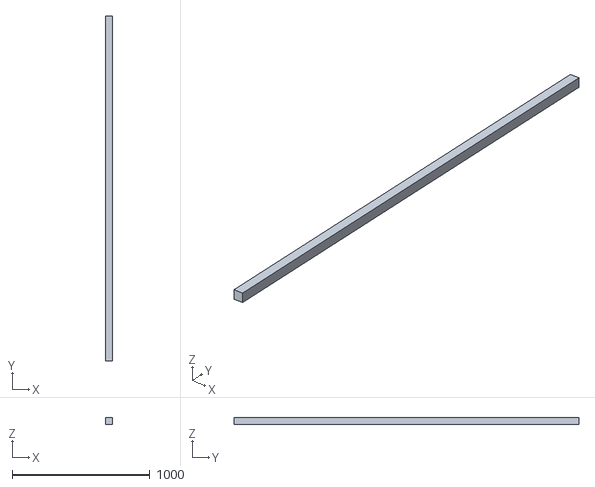
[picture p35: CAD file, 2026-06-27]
CAD/photobioreactor/Слобик остекления.stl
50.0 x 2500.0 x 50.0

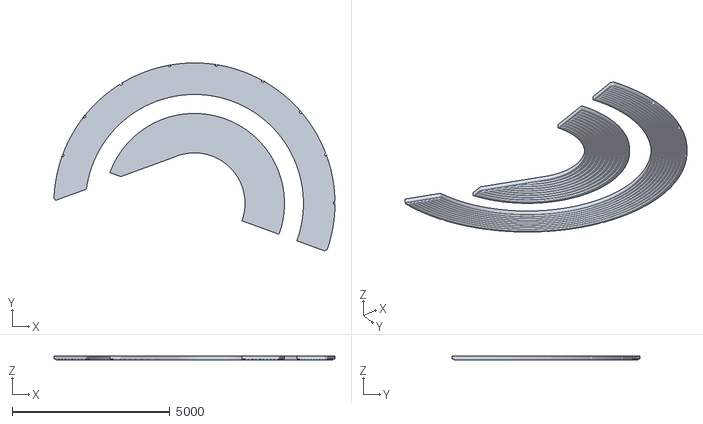
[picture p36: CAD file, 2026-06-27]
CAD/aeroponic/Свет.stl
8896.1 x 5955.7 x 130.0

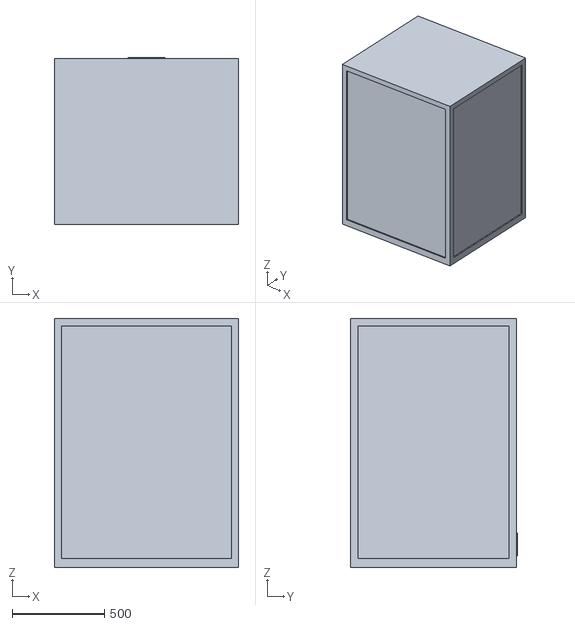
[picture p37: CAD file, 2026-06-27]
CAD/insects/Террариум.stl
1000.0 x 905.0 x 1350.0

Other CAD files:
CAD/other/Рабочее место.stl
CAD/photobioreactor/Сегмент_внутр_сегмент.stl
CAD/aeroponic/Доп опора 2.stl
CAD/insects/Дно — толст.stl
CAD/aeroponic/Сборка пол с балками и этажом.stl
CAD/insects/Дно ящики.stl
CAD/insects/Переборка между лич и тер.stl
CAD/insects/Переборка.stl
CAD/insects/Сегмент для личинок держалка 2.stl
CAD/insects/Сегмент для личинок цилиндр.stl
CAD/insects/Сегмент для личинок.stl
CAD/insects/Стенки терр.stl
CAD/insects/Ящики верх.stl
CAD/other/верх платформы.stl
CAD/photobioreactor/Освещение внутр.stl
CAD/photobioreactor/Освещение правильное.stl
CAD/photobioreactor/Сегмент_внешн_сегмент.stl
CAD/photobioreactor/Слобик остекления мал.stl
CAD/photobioreactor/Фотобиореактор_база.stl

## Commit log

2026-06-27 Переведён README.md на русский язык
    Обновлён README.md для описания биорегенеративной системы жизнеобеспечения на русском языке.
2026-06-27 add "CAD" folder with files
    [Доп опора 1.stl, Доп опора 2.stl, Пол.stl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]
2026-06-27 add folders
    [Дно ящики.stl, Дно — толст.stl, Освещение внутр.stl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]
2026-06-27 add folder with other CADs
    [Проект для 3д принтера.3mf, Рабочее место.stl, верх платформы дуга.stl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]
